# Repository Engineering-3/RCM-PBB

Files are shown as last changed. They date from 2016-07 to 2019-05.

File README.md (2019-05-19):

# RCM-PBB

RCM-PBB

RCM Power Buss Board

This is a power distribution board to be used independently or with the RCM Control Stack. The RCM-PBB is designed to supply a regulated 9V to each of the five outputs from a higher voltage battery. It features Anderson PowerPole battery connectors and a SPST on-off switch. Please see [Engineering3](http://engineering3.org/) for more information on the complete RCM Control Stack project.

Repository Contents
-------------------

* **/RCM-PBB_v1** Eagle schematic/board files, BOM, gerbers

Version History
---------------
* [RCM-PBB_v1](https://github.com/Engineering-3/RCM-PBB/tree/master/RCM-PBB_v1) - First public version - version 1 

License Information
-------------------
Hardware is released under [Solderpad Hardware License v0.51](http://solderpad.org/licenses/SHL-0.51/).
Distributed as-is; no warranty is given.

Getting Started Help
--------------------
This is a Plug-n-Play board.

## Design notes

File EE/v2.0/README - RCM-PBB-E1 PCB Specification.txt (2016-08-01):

RCM-PBB-E1 PCB Specification
-------------------------------

BOARD STACK:

1. Copper Top
2. Copper Bottom

SILKSCREENS:

1.  Both Layers

PASTE MASKS:

1. Top Layer

BOARD MATERIALS:

RoHS Compliant: YES
Copper: 2oz  ************************************
Finish: Immersion Gold
Material: FR-406
Thickness: 62 mil
Tg>170
Soldermask: SMOBC BLUE
Silkscreen: White

BOARD TESTING:

Electrical Test: YES

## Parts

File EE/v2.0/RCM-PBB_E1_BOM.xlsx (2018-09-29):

Reference Designator | MFR | MFR Part Number | Digikey Part Number | Qty | Notes | 10-Price | 10-Qty | 10-Total | 100-Price | 100-Qty | 100-Total
C3,5,6,9,10,11,13 | Murata | GRM21BR71E104KA01L | 490-1673-1-ND | 7 | CAP0805 |  | 70 |  |  | 735
C1,2 | Panasonic | EEE-1VA101XP | PCE3951CT-ND | 2 | CAP ALUM 100UF 35V 20% SMD D8-ELT-CAP |  | 20 |  |  | 210
C4,7,8 | Murata | C0805C474K3RACTU | 399-8098-1-ND | 3 | CAP CER .47UF 25V 10% X7R 0805 |  | 30 |  |  | 315
D3 | Diodes Inc | BAS40-05-7-F | BAS40-05-FDICT-ND | 1 | DIODE SCHTKY 350MW 40V SOT23-3 |  | 10 |  |  | 105
J1 | Anderson Power | 1327 | 879-1327 | 1 | ANDERSON_POWER_POLE RED |  | 10 |  |  | 105
J2 | Anderson Power | 1327G6 | 879-1327G6 | 1 | ANDERSON_POWER_POLE BLACK |  | 10 |  |  | 105
J1,2 | Anderson Power | 1399G8-BK | 879-1399G8-BK | 2 | ANDERSON_POWER_POLE BLUE WINGS |  | 20 |  |  | 210
J1,2 | Anderson Power | 1317G3 | 879-1377G4-BK | 2 | ANDERSON_POWER_25A STRAIGHT PINS |  | 20 |  |  | 210
J3,4,5,6,7 | Molex | 70553-0036 | WM4924-ND | 5 | CONN HDR RT ANG 2POS .100 TIN |  | 50 |  |  | 525
LED3 | Lite-On Inc | LTST-C171CKT | 160-1421-1-ND | 1 | LED ALGAAS RED THIN 0805 SMD |  | 10 |  |  | 105
LED1 | Lite-On Inc | LTST-C171GKT | 160-1423-1-ND | 1 | LED GREEN CLEAR THIN 0805 SMD |  | 10 |  |  | 105
LED2 | Lite-On Inc | LTST-C171YKT | 160-1431-1-ND | 1 | LED YELLOW CLEAR THIN 0805 SMD |  | 10 |  |  | 105
Q1 | ON Semiconductor | MUN2211T1G | MUN2211T1GOSCT-ND | 1 | TRANS BRT NPN 100MA 50V SC59 |  | 10 |  |  | 105
R1 | Rohm Semiconductor | MCR10ERTF1000 (http://www.digikey.com/product-detail/en/MCR10ERTF1000/RHM100CHCT-ND/2796511) | RHM100CHCT-ND | 1 | RES SMD 100 OHM 1% 1/8W 0805 |  | 10 |  |  | 105
R3 | Rohm Semiconductor | MCR10ERTF7500 (http://www.digikey.com/product-detail/en/MCR10ERTF7500/RHM750CHCT-ND/4084981) | RHM750CHCT-ND | 1 | RES SMD 750 OHM 1% 1/8W 0805 |  | 10 |  |  | 105
R2,4,5 | Rohm Semiconductor | MCR10ERTF1001 (http://www.digikey.com/product-detail/en/MCR10ERTF1001/RHM1.00KCHCT-ND/2796512) | RHM1.00KCHCT-ND | 3 | RES SMD 1k OHM 1% 1/8W 0805 |  | 30 |  |  | 315
R6,7 | Rohm Semiconductor | MCR10ERTF2400 (http://www.digikey.com/product-detail/en/MCR10ERTF2400/RHM240CHCT-ND/4084696) | RHM240CHCT-ND | 2 | RES SMD 240 OHM 1% 1/8W 0805 |  | 20 |  |  | 210
R8 | Rohm Semiconductor | MCR10ERTF7153 (http://www.digikey.com/product-detail/en/MCR10ERTF7153/RHM715KCHCT-ND/4084974) | RHM715KCHCT-ND | 1 | RES SMD 715K OHM 1% 1/8W 0805 |  | 10 |  |  | 105
R9 | Rohm Semiconductor | MCR10ERTF6193 (http://www.digikey.com/product-detail/en/MCR10ERTF6193/RHM619KCHCT-ND/4084934) | RHM619KCHCT-ND | 1 | RES SMD 619K OHM 1% 1/8W 0805 |  | 10 |  |  | 105
R15,16 | Rohm Semiconductor | MCR10ERTF1002 (http://www.digikey.com/product-detail/en/MCR10ERTF1002/RHM10.0KCHCT-ND/2796513) | RHM10.0KCHCT-ND | 2 | RES SMD 10K OHM 1% 1/8W 0805 |  | 20 |  |  | 210
R11 | Rohm Semiconductor | MCR10ERTF4992 (http://www.digikey.com/product-detail/en/MCR10ERTF4992/RHM49.9KCHCT-ND/4084880) | RHM49.9KCHCT-ND | 1 | RES SMD 49.9K OHM 1% 1/8W 0805 |  | 10 |  |  | 105
R12 | Rohm Semiconductor | MCR10ERTF1912 (http://www.digikey.com/product-detail/en/MCR10ERTF1912/RHM19.1KCHCT-ND/4084644) | RHM19.1KCHCT-ND | 1 | RES SMD 19.1K OHM 1% 1/8W 0805 |  | 10 |  |  | 105
R13 | Rohm Semiconductor | MCR10ERTF9311 (http://www.digikey.com/product-detail/en/MCR10ERTF9311/RHM9.31KCHCT-ND/4085036) | RHM9.31KCHCT-ND | 1 | RES SMD 9.31K OHM 1% 1/8W 0805 |  | 10 |  |  | 105
R10 | Rohm Semiconductor | MCR10ERTF1052 (http://www.digikey.com/product-detail/en/MCR10ERTF1052/RHM10.5KCHCT-ND/4084480) | RHM10.5KCHCT-ND | 1 | RES SMD 10.5K OHM 1% 1/8W 0805 |  | 10 |  |  | 105
R18 | Rohm Semiconductor | MCR10EZPF1004 | RHM1.00MCRCT-ND | 1 | RES 1.00M OHM 1/8W 1% 0805 SMD |  | 10 |  |  | 105
S1 | E-Switch | 500SSP1S1M6QEA | EG2478-ND | 1 | SWITCH SLIDE SPDT SILVR 5A RTANG |  | 10 |  |  | 105
U1 | Fairchild Semiconductor | MC78L05ACHX | MC78L05ACHXCT-ND | 1 | IC VREG 100MA 5V SOT-89 |  | 10 |  |  | 105
Alt U1 | STMicroelectronics | L78L05ABUTR | 497-1181-1-ND | 1 | IC REG LINEAR 5V 100MA SOT89-3 |  | 10 |  |  | 105
U5 | Micro Chip Technology | MCP6542-E/MS | MCP6542-E/MS-ND | 1 | IC COMP 1.6V DUAL P-P 8MSOP |  | 10 |  |  | 105
U6,7 | NXP Semiconductors | 74LVC1G74DC,125 | 568-4494-1-ND | 2 | IC SNGL D FF POS-EDG TRIG 8VSSOP |  | 20 |  |  | 210
U2 | Micrel | MIC29502WU | 576-1146-1-ND | 1 | IC REG LDO ADJ 5A TO263-5 |  | 10 |  |  | 105
PCB | Xtreme | EN3-RCM-PBB-PCB+E1 | EN3-RCM-PBB-PCB+E1 | 1 | EN3-RCM-PBB-PCB+E1 |  | 8 |  |  | 100

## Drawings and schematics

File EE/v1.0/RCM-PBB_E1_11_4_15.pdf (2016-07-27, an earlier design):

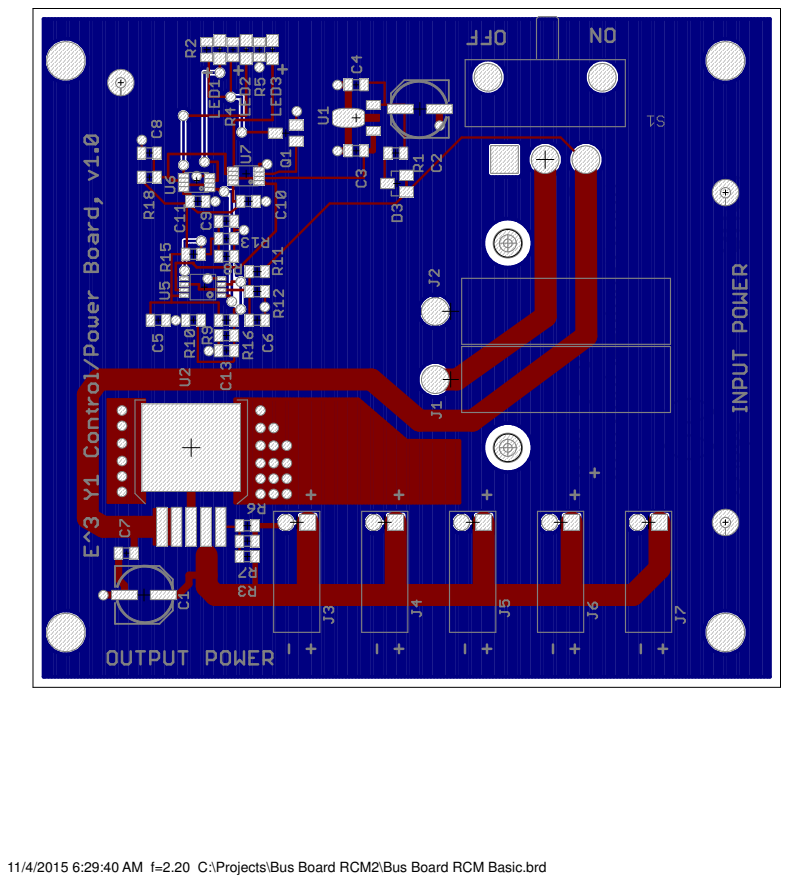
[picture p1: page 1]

11/4/2015 6:29:40 AM f=2.20 C:\Projects\Bus Board RCM2\Bus Board RCM Basic.brd

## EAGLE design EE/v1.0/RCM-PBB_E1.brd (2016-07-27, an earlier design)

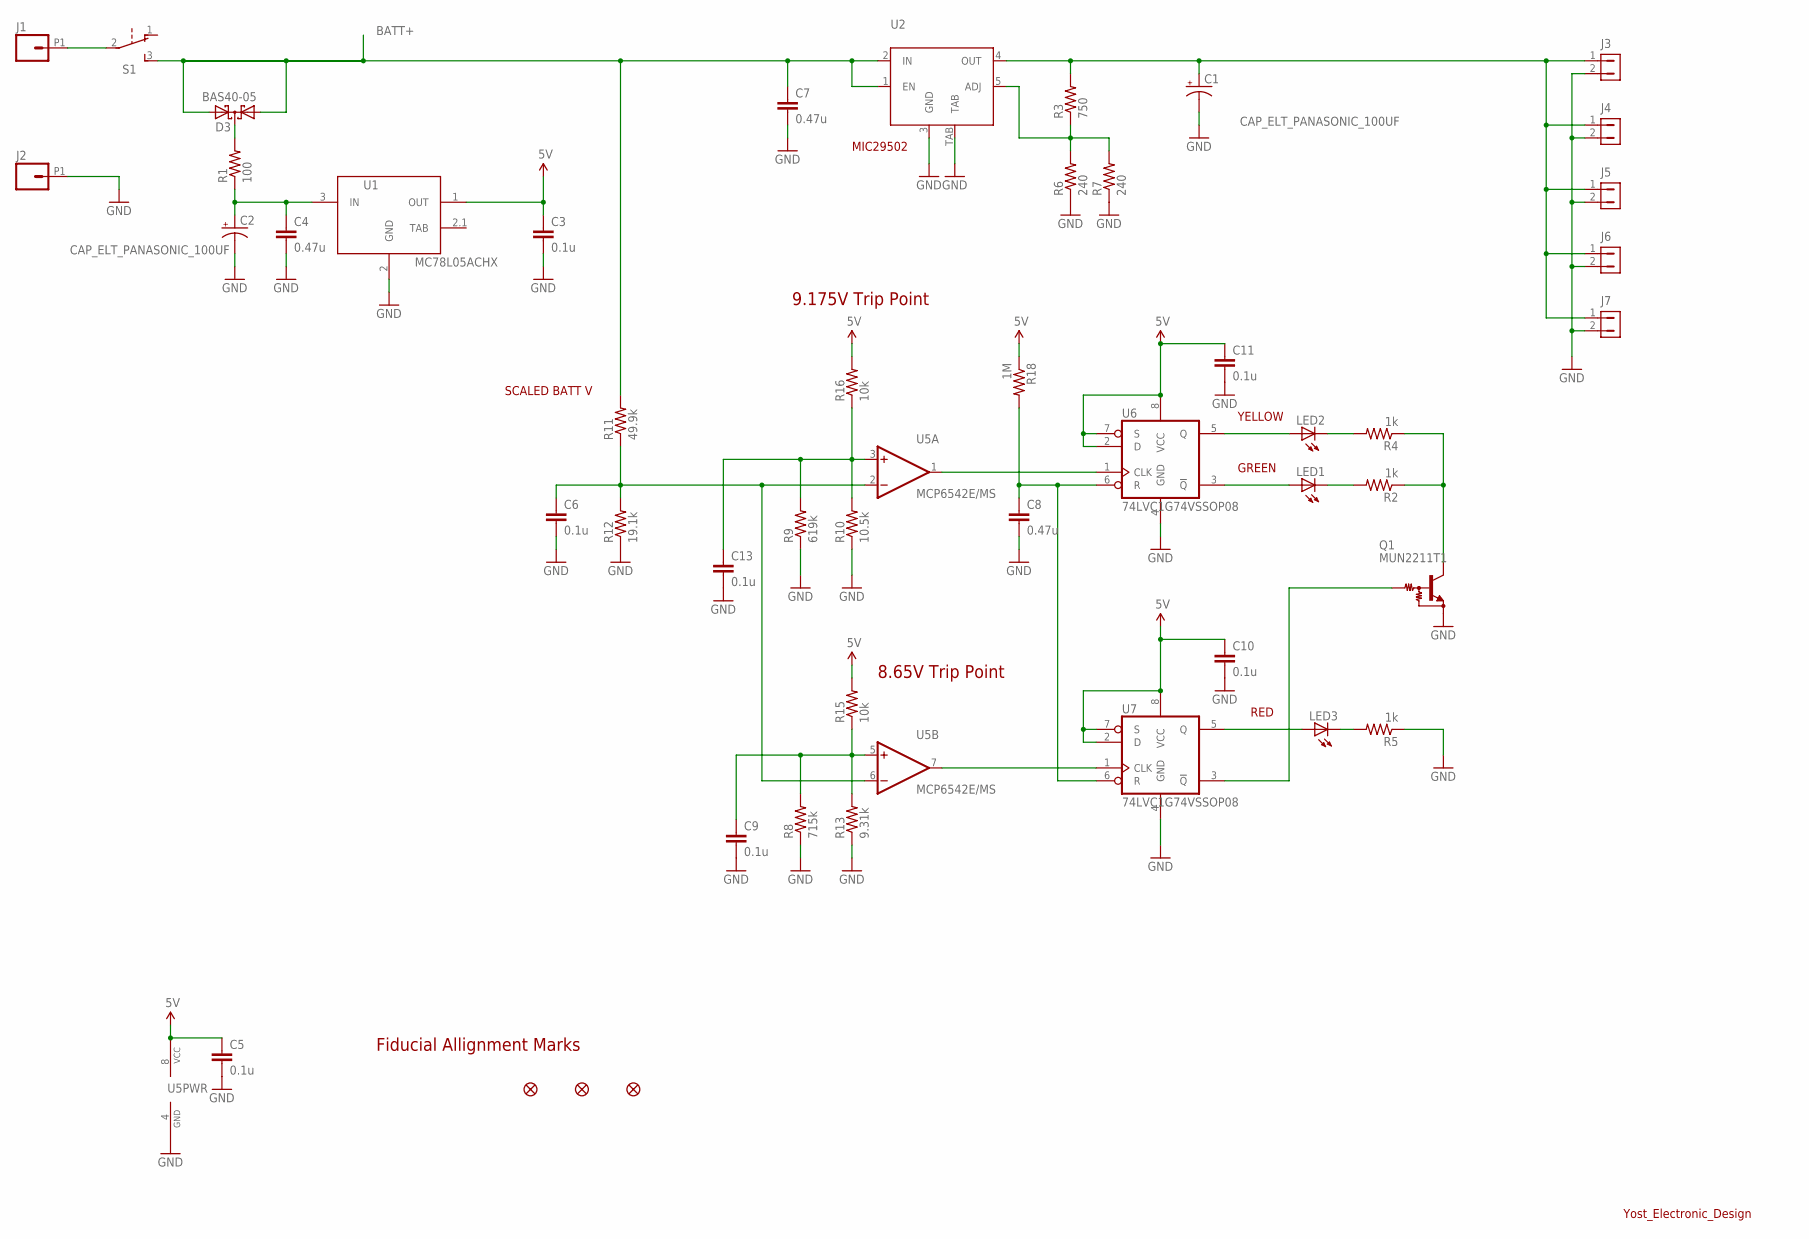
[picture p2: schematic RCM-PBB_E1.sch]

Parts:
C1, C2: CAP_ELT_PANASONIC_100UF; PANASONIC-D8-ELT-CAP
C3, C5, C6, C9, C10, C11, C13: 0.1u; 0805
C4, C7, C8: 0.47u; 0805
D3: BAS40-05; SOT23
J1, J2: ANDERSON_POWER_POLE
J3, J4, J5, J6, J7: CON1X2_SHROUDED; HEADER_1X2_SHROUDED
JP4, JP5, JP6: FIDUCIAL1X2.5; FIDUCIAL-1X2.5
LED1, LED2, LED3: LEDCHIPLED_0805; CHIPLED_0805
Q1: MUN2211T1; SC59-BEC
R1: 100; 0805
R2, R4, R5: 1k; 0805
R3: 750; 0805
R6, R7: 240; 0805
R8: 715k; 0805
R9: 619k; 0805
R10: 10.5k; 0805
R11: 49.9k; 0805
R12: 19.1k; 0805
R13: 9.31k; 0805
R15, R16: 10k; 0805
R18: 1M; 0805
S1: SWITCH_SLIDE_ON_ON; SWITCH_SLIDE_RA
U1: MC78L05ACHX; SOT89
U2: MIC29502WU; TO263-5
U5: MCP6542E/MS; MSOP8NOPAD
U6, U7: 74LVC1G74VSSOP08; VSSOP08

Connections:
5V: C3.1, C5.1, C10.1, C11.1, R15.2, R16.2, R18.1, U1.1 (OUT), U5.8 (VCC), U6.2 (D), U6.7 (S), U6.8 (VCC), U7.2 (D), U7.7 (S), U7.8 (VCC)
BATT+: C7.1, D3.1 (A1), D3.2 (A2), R11.2, S1.3 (S), U2.1 (EN), U2.2 (IN)
GND: C1.-, C2.-, C3.2, C4.2, C5.2, C6.2, C7.2, C8.2, C9.2, C10.2, C11.2, C13.2, J2.P1, J3.2, J4.2, J5.2, J6.2, J7.2, Q1.E, R5.1, R6.1, R7.1, R8.1, R9.1, R10.1, R12.1, R13.1, U1.2 (GND), U2.3 (GND), U2.TAB, U5.4 (GND), U6.4 (GND), U7.4 (GND)
unnamed: D3.3 (C), R1.2
unnamed: C13.1, R9.2, R10.2, R16.1, U5.3 (+IN)
unnamed: LED1.C, R2.2
unnamed: U5.1 (OUT), U6.1 (CLK)
unnamed: C8.1, R18.2, U6.6 (R), U7.6 (R)
unnamed: U5.7 (OUT), U7.1 (CLK)
unnamed: Q1.C, R2.1, R4.1
unnamed: C1.+, J3.1, J4.1, J5.1, J6.1, J7.1, R3.2, U2.4 (OUT)
unnamed: LED3.A, U7.5 (Q)
unnamed: J1.P1, S1.2
unnamed: LED1.A, U6.3 (!Q)
unnamed: C9.1, R8.2, R13.2, R15.1, U5.5 (+IN)
unnamed: LED3.C, R5.2
unnamed: C6.1, R11.1, R12.2, U5.2 (-IN), U5.6 (-IN)
unnamed: C2.+, C4.1, R1.1, U1.3 (IN)
unnamed: LED2.C, R4.2
unnamed: LED2.A, U6.5 (Q)
unnamed: Q1.B, U7.3 (!Q)
unnamed: R3.1, R6.2, R7.2, U2.5 (ADJ)

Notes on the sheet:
Yost_Electronic_Design
SCALED BATT V
GREEN
RED
YELLOW
8.65V Trip Point
Fiducial Allignment Marks
9.175V Trip Point
MIC29502

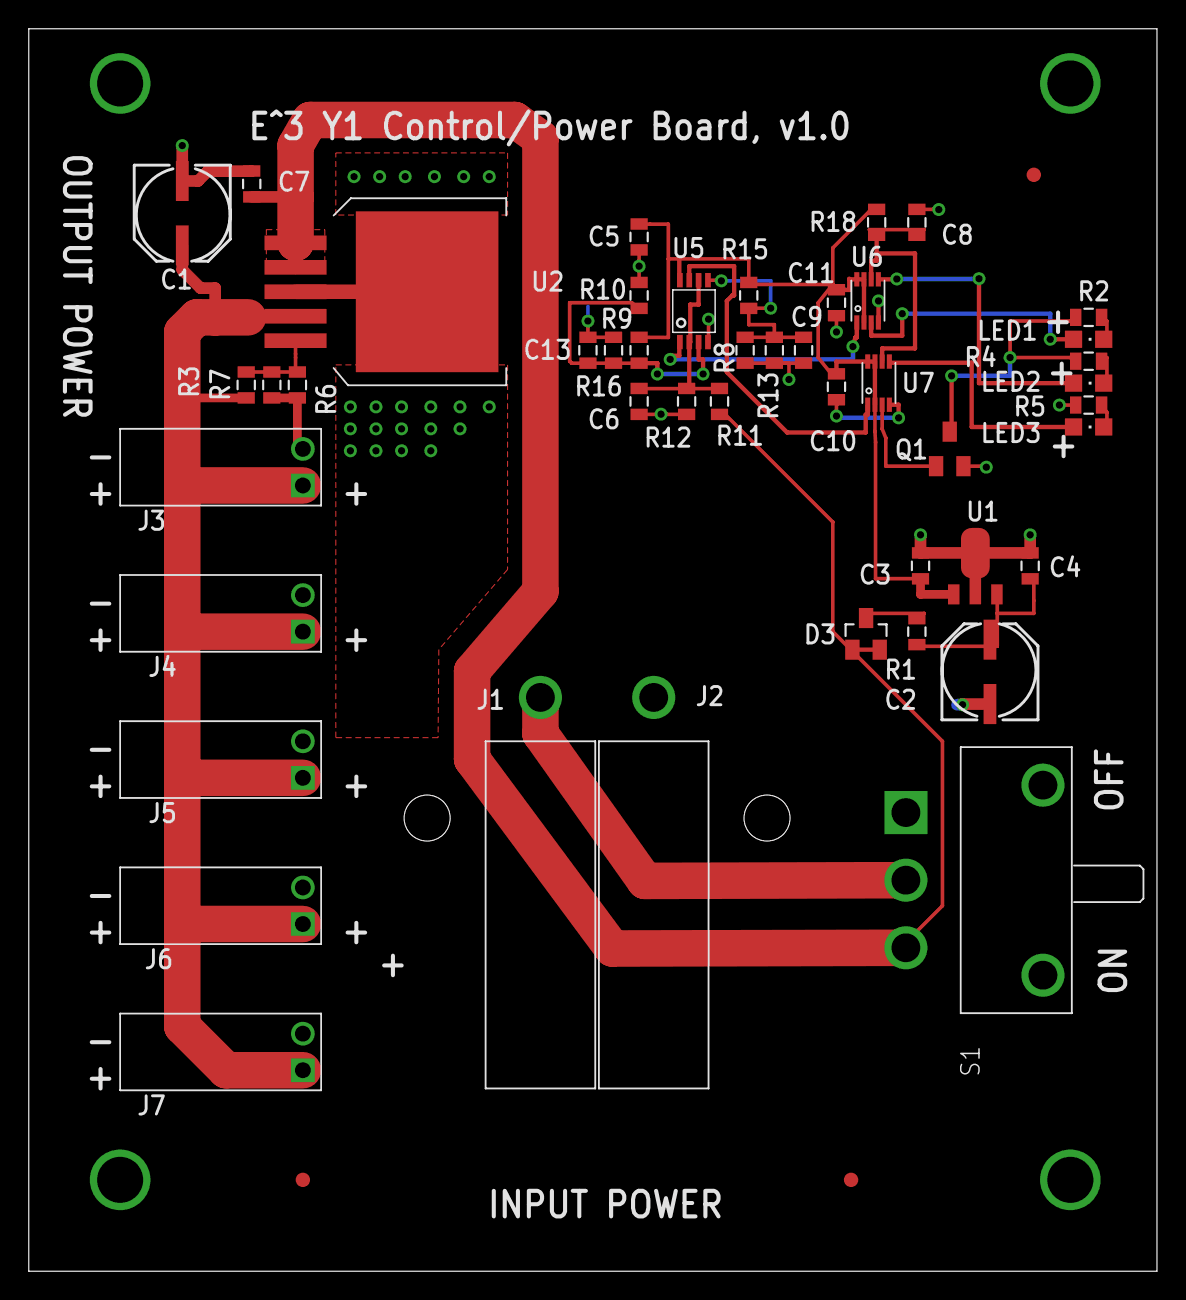
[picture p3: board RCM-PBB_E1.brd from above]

Board: 2 copper layers, 78.4 x 86.3 mm, 49 parts (0 on the bottom side), 22 nets.

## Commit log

2016-07-27 Initial check in of E1 version of Power Buss Board. Includes v1 and v2 versions of the board.
    [Bus Board RCM Basic.brd, Bus Board RCM Basic.sch, RCM-PBB_E1.brd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]
2016-07-28 Renaming some files for v1.0, and adding BOM Excel file.
    [RCM-PBB_E1.brd, RCM-PBB_E1.sch, RCM-PBB_E1_BOM.xlsx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]
2016-07-28 Fixed minor error in BOM.
    [RCM-PBB_E1_BOM.xlsx, RCM-PBB_E1_BOM_9_25_15.xlsx]
2016-07-28 Fixed another minor error in the BOM, updated filenames.
    [RCM-PBB_E1_BOM_12_17_15.xlsx, RCM-PBB_E1_BOM_9_25_15.xlsx]
2016-08-01 Added board build readme.
    [RCM-PBB_E1.GBL, RCM-PBB_E1.GBO, RCM-PBB_E1.GBS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]
2018-09-29 Added alternate 5V LDO for U1.
    [RCM-PBB_E1_BOM.xlsx]

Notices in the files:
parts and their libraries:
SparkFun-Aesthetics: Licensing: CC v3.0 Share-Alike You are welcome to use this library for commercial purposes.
